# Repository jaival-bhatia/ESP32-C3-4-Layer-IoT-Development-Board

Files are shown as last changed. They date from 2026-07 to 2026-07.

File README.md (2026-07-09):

# ESP32-C3-4-Layer-IoT-Development-Board
A custom-designed 4-layer ESP32-C3 IoT development board featuring USB Type-C, Li-ion battery management, environmental sensing, OLED display, and expandable peripheral interfaces.

<div align="center">

PCB Render

**A Custom 4-Layer ESP32-C3 Development Board for Battery-Powered IoT Applications**

[]()
[]()
[]()
[]()
[]()
[]()

</div>

---

# Overview

This project presents a **custom-designed 4-layer ESP32-C3 IoT Development Board** built for low-power, battery-operated embedded applications. The board combines wireless connectivity, intelligent power management, onboard environmental sensing, expandable storage, and a compact PCB layout into a single development platform.

The primary objective of this project was to design a production-ready embedded hardware platform capable of supporting rapid IoT prototyping while following professional PCB design practices such as dedicated power and ground planes, optimized signal routing, proper decoupling, and manufacturing-ready documentation.

Designed entirely in **KiCad**, the board integrates battery charging, USB Type-C connectivity, environmental sensing, local data storage, and display capabilities, making it suitable for a wide range of embedded applications.

---

# Key Features

- 4-Layer PCB designed using KiCad
- ESP32-C3 Wi-Fi + Bluetooth Low Energy (BLE) SoC
- USB Type-C interface for programming and charging
- TP4056 Li-ion battery charging circuit
- Single-cell Li-ion battery support
- Onboard BME280 environmental sensor
- Ambient Light Sensor
- Sound Sensor Interface
- I²C OLED Display Connector
- SPI Flash Memory
- MicroSD Card Storage
- Battery Status LEDs
- Low-Power Embedded Design
- Expandable GPIO Header
- Manufacturing Ready (ERC/DRC Verified)

---

# Hardware Specifications

| Parameter | Description |
|---|---|
| Microcontroller | ESP32-C3 |
| PCB Layers | 4 |
| Power Input | USB Type-C |
| Battery | 3.7V Li-ion |
| Charging IC | TP4056 |
| Connectivity | Wi-Fi + BLE |
| Display | OLED (I²C) |
| Sensors | BME280, Ambient Light, Sound |
| Storage | SPI Flash + microSD |
| Design Software | KiCad |

---

# System Architecture

```
                  USB Type-C
                       │
                       ▼
                TP4056 Charger
                       │
         ┌─────────────┴─────────────┐
         │                           │
         ▼                           ▼
   Li-ion Battery              USB Power
         │                           │
         └─────────────┬─────────────┘
                       ▼
                 3.3V Regulation
                       │
                       ▼
                  ESP32-C3 MCU
      ┌────────┬────────┬────────┬────────┐
      │        │        │        │
      ▼        ▼        ▼        ▼
   OLED     BME280   Flash    microSD
      │
      ▼
 Additional Sensors & GPIO Expansion
```

---

# Power Architecture

The board supports dual power operation through USB Type-C and a rechargeable Li-ion battery.

Power flow:

```
USB Type-C
      │
      ▼
TP4056 Charger
      │
      ▼
Li-ion Battery
      │
      ▼
Voltage Regulation
      │
      ▼
ESP32-C3 + Peripherals
```

The TP4056 charging IC provides:

- Constant Current Charging
- Constant Voltage Charging
- Automatic Charge Termination
- Thermal Protection
- Battery Status Indication

This enables safe battery charging while simultaneously powering the embedded system.

---

# Major Components

| Component | Function |
|---|---|
| ESP32-C3 | Main Microcontroller |
| TP4056 | Li-ion Battery Charger |
| USB Type-C | Power & Programming |
| BME280 | Temperature, Humidity & Pressure |
| OLED Display | Real-time Visualization |
| Flash Memory | Firmware/Data Storage |
| microSD | External Data Logging |

---

# PCB Design Highlights

Highlights include:

- 4-Layer PCB Stack-up
- Dedicated Ground Plane
- Dedicated Power Plane
- Optimized Component Placement
- Short High-Speed Signal Routing
- Proper Decoupling Capacitor Placement
- Optimized Power Distribution
- Low-Noise Analog Routing
- Manufacturing Ready Layout
- ERC & DRC Verified

## Schematics

| Sheet | Description |
|---|---|
| Sheet 1 | USB Type-C & Power Input |
| Sheet 2 | ESP32-C3 Core Circuit |
| Sheet 3 | Sensors & Interfaces |
| Sheet 4 | Battery Charging & Peripheral Connections |






PCB 1st Layer


PCB 2nd Layer


PCB 3rd Layer


PCB 4th Layer


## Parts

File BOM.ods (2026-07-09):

DESIGNATOR | QTY | VALUE | MANUF. PART No | MANUFACTURER | PACKAGE | DESCRIPTION
C1, C2, C5, C8, C10, C13-C16, C18, C21, C23 | 12 | 0.1u | C0805C104K4RAC | KEMET | 0805 | Multilayer Ceramic Capacitors MLCC - SMD/SMT 16V 0.1uF X7R 0805 10%
C3, C4, C7, C12 | 4 | 10u | T491A106K010AT7280 | KEMET | 1206 | T491, Tantalum, MnO2 Tantalum, Commercial Grade, 10 uF, 10%, 10 VDC, 125C, -55C, 85C, SMD, MnO2, Molded, 6 % , 3.8 Ohms, 1000 nA, 58.6 mg, 3216, 1.6mm, Height Max = 1.8mm, 9000, 156 Weeks
C6, C11, C22 | 3 | 1u | C0805C105K4RACTU | KEMET | 0805 | Multilayer Ceramic Capacitors MLCC - SMD/SMT 16V 1uF X7R 0805 10%
C9 | 1 | 4.7u | T491A475K010AT7280 | KEMET | 1206 | T491, Tantalum, MnO2 Tantalum, Commercial Grade, 4.7 uF, 10%, 10 VDC, 125C, -55C, 85C, SMD, MnO2, Molded, 6 % , 4 Ohms, 500 nA, 58.6 mg, 3216, 1.6mm, Height Max = 1.8mm, 9000, 156 Weeks
C17, C24, C25 | 3 | 10n | C0603C103K4RACTU | KEMET | 0603 | Multilayer Ceramic Capacitors MLCC - SMD/SMT 16V 0.01uF X7R 0603 10%
C19 | 1 | 10uF | C1206C106K4RAC | KEMET | 1206 | Multilayer Ceramic Capacitors MLCC - SMD/SMT 16V 10uF X7R 1206 10%
C20 | 1 | 100pF | C0603C101K4RACTU | KEMET | 0603 | Multilayer Ceramic Capacitors MLCC - SMD/SMT 16V 100pF X7R 0603 10%
D1, D4, D6 | 3 | RED | LTST-C170KRKT | Lite-On | 0805 | Standard LEDs - SMD Red Clear 631nm
D2, D5 | 2 | GREEN | LTST-C170GKT | Lite-On | 0805 | LED,SMD,0805,Green,6mcd,130deg Lite-On LTST-C170GKT, CHIPLED 0805 Series Green LED, 569 nm 2012 (0805), Rectangle Lens SMD package
D3 | 1 | BLUE | LTST-C170TBKT | Lite-On | 0805 | LED,SMD,0805,Blue,28mcd,130deg
F1 | 1 | 0ZCH0110AF2E | 0ZCH0110AF2E | Belfuse | 1210 | 1210 SMT PPTC | 1.10 Ih | 16V
J1 | 1 | USB_C_Receptacle | SS-52400-002 | STEWART CONNECTOR | USB Type-C | USB 2.0-only Type-C Receptacle connector
J2 | 1 | JST_2mm_LiPo | PHR-2 | JST |  | 2 Pin 2mm JST Battery Connector
J3 | 1 | GSD090012SEU | GSD090012SEU | Amphenol |  | Memory Card Connectors SD CARD CONNECTOR 9 POS, SMT
J4, J5 | 2 | B4B-XH-AM | B4B-XH-AM | JST |  | Connector header vertical 4pos 2.5mm
J6 | 1 | Conn_01x05 |  |  |  | Header 1X5, 2.54mm
L1 | 1 |  | FBMJ2125HM330 | TAIYO YUDEN | 0805 | Ferrite Bead 0805 4A 33OHMS 25%
MK1 | 1 | CMC-5042PF-AC | CMC-5042PF-AC | CUI INC
Q1 | 1 | TEMT6000X01 | TEMT6000X01 | VISHAY | 4 mm x 2 mm x 1.05 mm | Ambient Light Sensors Ambient Light Sensor AEC-Q101 Qualified
Q2, Q3 | 2 | BC817 | BC817 |  | SOT-23 | 0.8A Ic, 45V Vce, NPN Transistor, SOT-23
R1, R2, R19, R23, R32-R34 | 7 | 10K |  |  | 805 | SMD resistor, 0805, 125mW, 1%
R3, R4 | 2 | 5k1 |  |  | 0805 | SMD resistor, 0805, 125mW, 1%
R5, R26, R28 | 3 | 2K |  |  | 0805 | SMD resistor, 0805, 125mW, 1%
R6 | 1 | 20K |  |  | 0805 | SMD resistor, 0805, 125mW, 1%
R7-R9 | 3 | 470 |  |  | 0805 | SMD resistor, 0805, 125mW, 1%
R10, R14, R18 | 3 | 330 |  |  | 0805 | SMD resistor, 0805, 125mW, 1%
R11, R30 | 2 | 1K |  |  | 0805 | SMD resistor, 0805, 125mW, 1%
R12 | 1 | 22K1 |  |  | 0805 | SMD resistor, 0805, 125mW, 1%
R13 | 1 | 47K5 |  |  | 0805 | SMD resistor, 0805, 125mW, 1%
R15-R17, R20-R22 | 6 | 50 |  |  | 0805 | SMD resistor, 0805, 125mW, 1%
R24, R25 | 2 | 4K7 |  |  | 0805 | SMD resistor, 0805, 125mW, 1%
R27, R29 | 2 | 1M |  |  | 0805 | SMD resistor, 0805, 125mW, 1%
R31 | 1 | 22K |  |  | 0805 | SMD resistor, 0805, 125mW, 1%
SW1, SW2 | 2 | TL3305AF260QG | TL3305AF260QG | E-Switch |  | Tactile Switches 50mA 12VDC SPST, NO 3.8mm Act 260gf
U1 | 1 | MCP73871 | MCP73871-4CCI/ML | Microchip | QFN-20 | Single cell, Li-Ion/Li-Po charge management controller
U2 | 1 | LM1117MPX-3.3_NOPB | LM1117MPX-3.3/NOPB | Texas Instruments | SOT-223-4 | Space saving 800-mA low-dropout linear regulator with internal current limit
U3 | 1 | ESP32-C3-WROOM-02-H4 | ESP32-C3-WROOM-02-H4 | Espressif |  | Multiprotocol Modules SMD module, ESP32-C3, 4MB SPI flash, PCB antenna
U4 | 1 | CP2102N-A02-GQFN20 | CP2102N-A02-GQFN20 | Silicon Laboratories | QFN20 | USB to UART Bridge
U5 | 1 | USBLC6-2SC6 | USBLC6-2SC6 | STMicroelectronics | SOT-23-6 | ESD Suppressors / TVS Diodes ESD Protection Low Cap
U6 | 1 | W25Q32JVSSIQ | W25Q32JVSSIQ | Winbond | SOIC-8 | NOR Flash spiFlash, 32M-bit, 4Kb Uniform Sector
U7 | 1 | BME280 | BME280 | Bosch | LGA-8 | Air Quality Sensor MEMS humidity, pressure and temperature sensor
U8 | 1 | MAX4466EXK+T | MAX4466EXK+T | Analog Devices Inc. | SC-70-5 | Microphone Preamplifier
VR1 | 1 | 35WR100KLFTR | 35WR100KLFTR | TT Electronics |  | Trimmer Resistor - SMD 3mm 100K Open Type

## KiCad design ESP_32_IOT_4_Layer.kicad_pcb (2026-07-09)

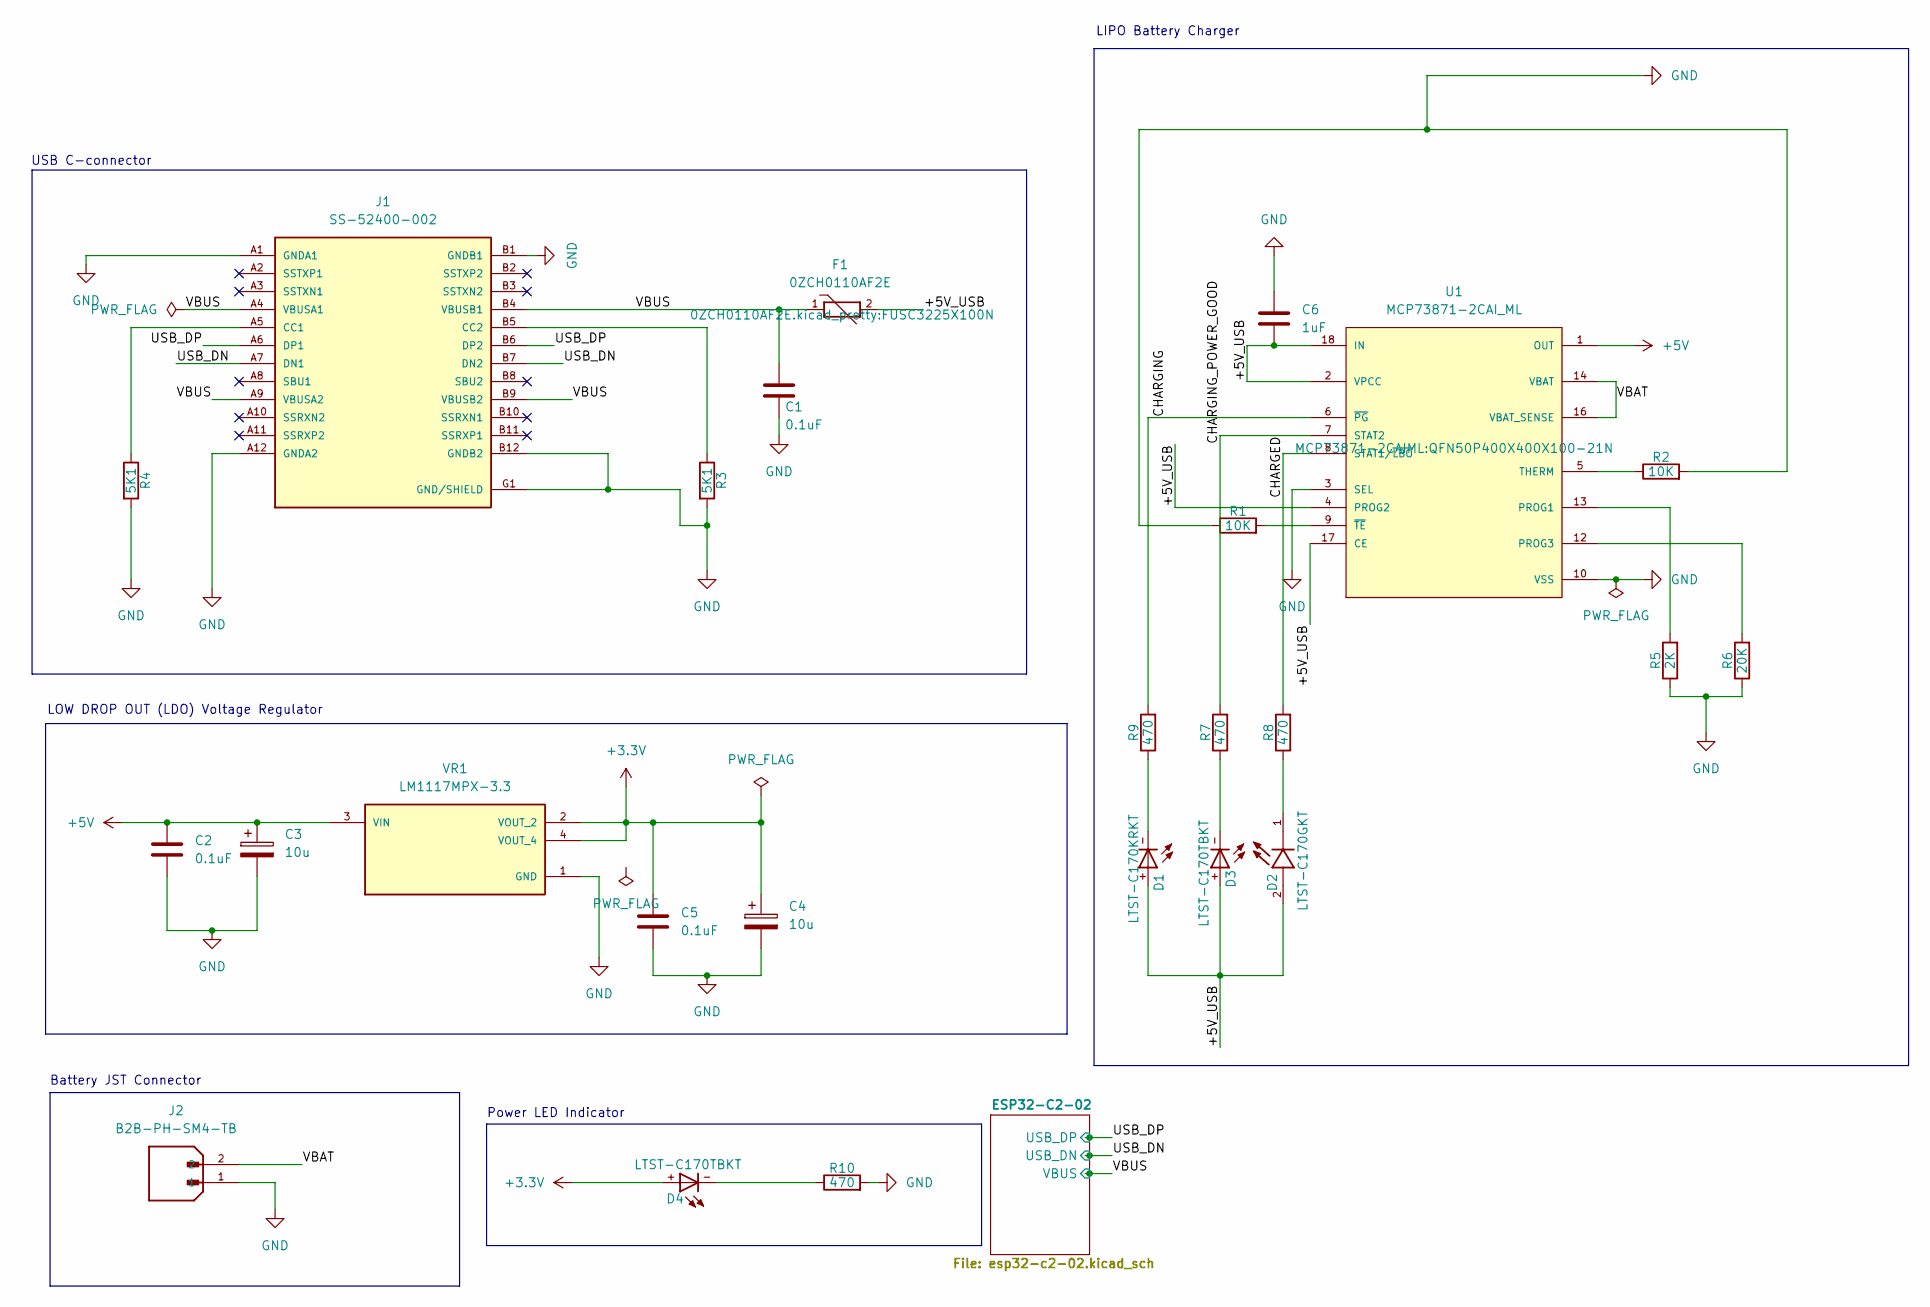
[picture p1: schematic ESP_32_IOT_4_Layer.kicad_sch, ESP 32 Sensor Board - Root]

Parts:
C1, C2, C5: 0.1uF; Fuse_0805_2012Metric
C3, C4: 10u; Fuse_0805_2012Metric
C6: 1uF; Fuse_0805_2012Metric
D1: LTST-C170KRKT; DIOC200X125X110; DigiKey_Part_Number 160-1415-1-ND
D2: LTST-C170GKT; LED_LTST-C170GKT; PARTREV I; DigiKey_Part_Number 160-1179-1-ND
D3, D4: LTST-C170TBKT; DIOC200X125X110; DigiKey_Part_Number 160-1579-1-ND
F1: 0ZCH0110AF2E; FUSC3225X100N; PARTREV Apr2023; DigiKey_Part_Number 5923-0ZCH0110AF2ECT-ND
J1: SS-52400-002; BELFUSE_SS-52400-003; PARTREV A0
J2: B2B-PH-SM4-TB; JST_B2B-PH-SM4-TB; PARTREV N/A
R1, R2: 10K; R_0805_2012Metric
R3, R4: 5K1; R_0805_2012Metric
R5: 2K; R_0805_2012Metric
R6: 20K; R_0805_2012Metric
R7, R8, R9, R10: 470; R_0805_2012Metric
U1: MCP73871-2CAI_ML; QFN50P400X400X100-21N; PARTREV D
VR1: LM1117MPX-3.3; VREG_LM1117MPX-3.3; PARTREV O

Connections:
+3.3V: C4.1, C5.1, D4.+, VR1.2 (VOUT_2), VR1.4 (VOUT_4); also elsewhere on the board
+5V: C2.1, C3.1, U1.1 (OUT), U1.20 (OUT), VR1.3 (VIN)
/+5V_USB: C6.2, D1.+, D2.2, D3.+, F1.2, U1.2 (VPCC), U1.4 (PROG2), U1.17 (CE), U1.18 (IN), U1.19 (IN)
/CHARGED: R8.2, U1.8 (STAT1/~LBO)
/CHARGING: R9.2, U1.6 (~PG)
/CHARGING_POWER_GOOD: R7.2, U1.7 (STAT2)
/USB_DN: J1.A7 (DN1), J1.B7 (DN2); also elsewhere on the board
/USB_DP: J1.A6 (DP1), J1.B6 (DP2); also elsewhere on the board
/VBAT: J2.2, U1.14 (VBAT), U1.15 (VBAT), U1.16 (VBAT_SENSE)
/VBUS: C1.1, F1.1, J1.A4 (VBUSA1), J1.A9 (VBUSA2), J1.B4 (VBUSB1), J1.B9 (VBUSB2); also elsewhere on the board
GND: C1.2, C2.2, C3.2, C4.2, C5.2, C6.1, J1.A1 (GNDA1), J1.A12 (GNDA2), J1.B1 (GNDB1), J1.B12 (GNDB2), J1.G1 (GND/SHIELD), J1.G2 (GND/SHIELD), J1.G3 (GND/SHIELD), J1.G4 (GND/SHIELD), J1.S1 (GND/SHIELD), J1.S2 (GND/SHIELD), J1.S3 (GND/SHIELD), J1.S4 (GND/SHIELD), J2.1, R1.1, R2.2, R3.2, R4.2, R5.1, R6.1, R10.2, U1.3 (SEL), U1.10 (VSS), U1.11 (VSS), U1.21 (VSS), VR1.1 (GND); also elsewhere on the board
unnamed: D1.-, R9.1
unnamed: D2.1, R8.1
unnamed: D3.-, R7.1
unnamed: D4.-, R10.1
unnamed: J1.A5 (CC1), R4.1
unnamed: J1.B5 (CC2), R3.1
unnamed: R5.2, U1.13 (PROG1)
unnamed: R6.2, U1.12 (PROG3)
unnamed: R2.1, U1.5 (THERM)
unnamed: R1.2, U1.9 (~TE)

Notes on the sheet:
LOW DROP OUT (LDO) Voltage Regulator
Power LED Indicator
Battery JST Connector
USB C-connector
LIPO Battery Charger

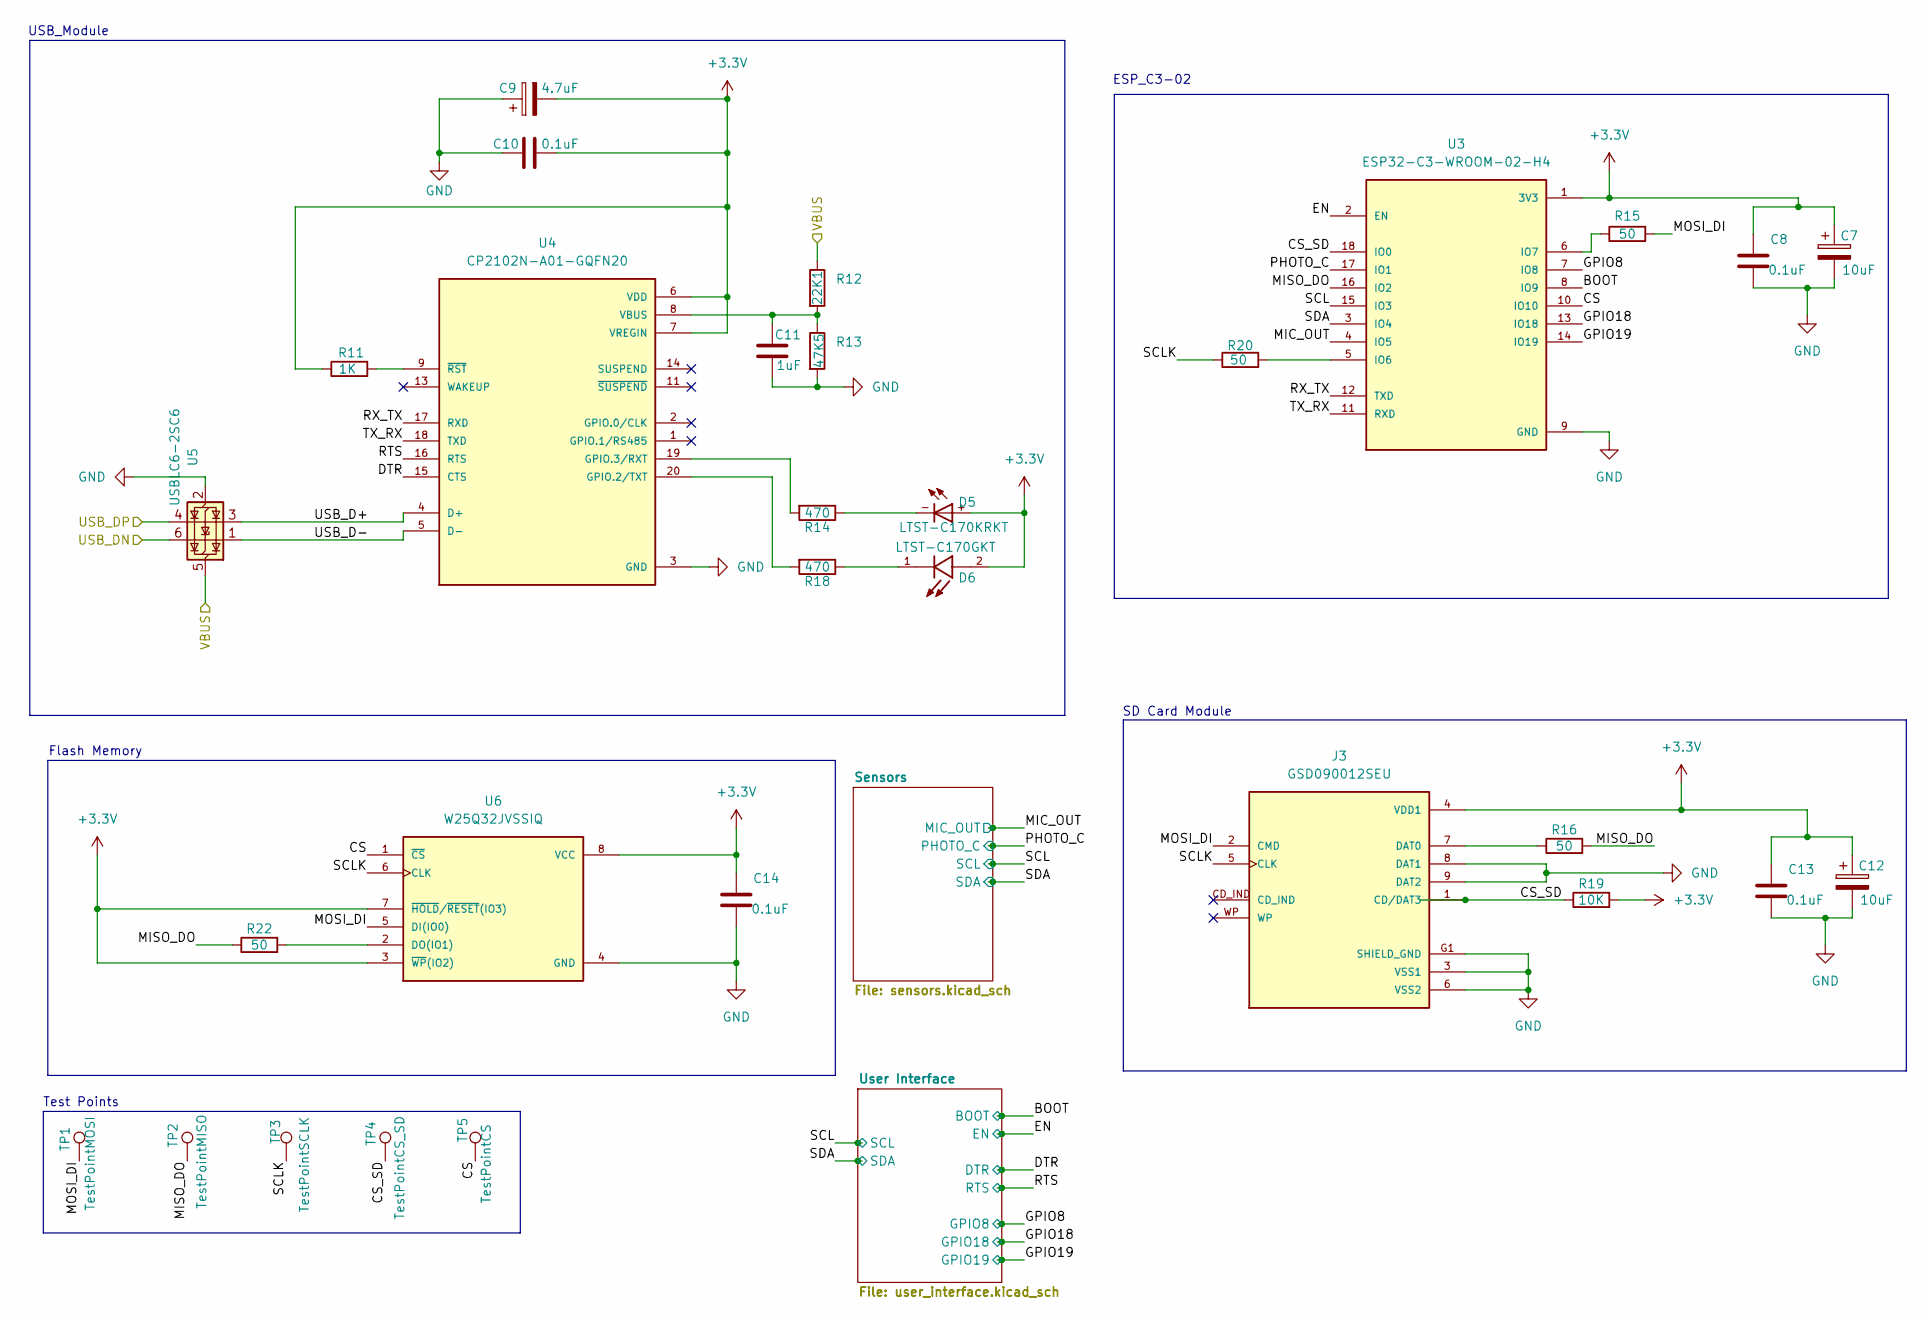
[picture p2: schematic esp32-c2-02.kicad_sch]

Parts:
C7, C12: 10uF; Fuse_0805_2012Metric
C8, C10, C13, C14: 0.1uF; Fuse_0805_2012Metric
C9: 4.7uF; Fuse_0805_2012Metric
C11: 1uF; Fuse_0805_2012Metric
D5: LTST-C170KRKT; DIOC200X125X110; DigiKey_Part_Number 160-1415-1-ND
D6: LTST-C170GKT; LED_LTST-C170GKT; PARTREV I; DigiKey_Part_Number 160-1179-1-ND
J3: GSD090012SEU; AMPHENOL_GSD090012SEU; PARTREV E
R11: 1K; R_0805_2012Metric
R12: 22K1; R_0805_2012Metric
R13: 47K5; R_0805_2012Metric
R14, R18: 470; R_0805_2012Metric
R15, R16, R20, R22: 50; R_0805_2012Metric
R19: 10K; R_0805_2012Metric
TP1: TestPointMOSI; TestPoint_Pad_D1.0mm
TP2: TestPointMISO; TestPoint_Pad_D1.0mm
TP3: TestPointSCLK; TestPoint_Pad_D1.0mm
TP4: TestPointCS_SD; TestPoint_Pad_D1.0mm
TP5: TestPointCS; TestPoint_Pad_D1.0mm
U3: ESP32-C3-WROOM-02-H4; MODULE_ESP32-C3-WROOM-02-H4
U4: CP2102N-A01-GQFN20; IC_CP2102N-A01-GQFN20
U5: USBLC6-2SC6; SOT95P280X145-6N
U6: W25Q32JVSSIQ; SOIC127P790X216-8N

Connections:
+3.3V: C7.1, C8.1, C9.2, C10.2, C12.1, C13.1, C14.1, D5.+, D6.2, J3.4 (VDD1), R11.1, R19.2, U3.1 (3V3), U4.6 (VDD), U4.7 (VREGIN), U6.3 (~WP(IO2)), U6.7 (~HOLD/~RESET(IO3)), U6.8 (VCC); also elsewhere on the board
/ESP32-C2-02/BOOT: U3.8 (IO9); also elsewhere on the board
/ESP32-C2-02/CS: TP5.1 (1_1), U3.10 (IO10), U6.1 (~CS)
/ESP32-C2-02/CS_SD: J3.1 (CD/DAT3), R19.1, TP4.1 (1_1), U3.18 (IO0)
/ESP32-C2-02/DTR: U4.15 (CTS); also elsewhere on the board
/ESP32-C2-02/EN: U3.2 (EN); also elsewhere on the board
/ESP32-C2-02/GPIO8: U3.7 (IO8); also elsewhere on the board
/ESP32-C2-02/GPIO18: U3.13 (IO18); also elsewhere on the board
/ESP32-C2-02/GPIO19: U3.14 (IO19); also elsewhere on the board
/ESP32-C2-02/MIC_OUT: U3.4 (IO5); also elsewhere on the board
/ESP32-C2-02/MISO_DO: R16.2, R22.1, TP2.1 (1_1), U3.16 (IO2)
/ESP32-C2-02/MOSI_DI: J3.2 (CMD), R15.2, TP1.1 (1_1), U6.5 (DI(IO0))
/ESP32-C2-02/PHOTO_C: U3.17 (IO1); also elsewhere on the board
/ESP32-C2-02/RTS: U4.16 (RTS); also elsewhere on the board
/ESP32-C2-02/RX_TX: U3.12 (TXD), U4.17 (RXD)
/ESP32-C2-02/SCL: U3.15 (IO3); also elsewhere on the board
/ESP32-C2-02/SCLK: J3.5 (CLK), R20.1, TP3.1 (1_1), U6.6 (CLK)
/ESP32-C2-02/SDA: U3.3 (IO4); also elsewhere on the board
/ESP32-C2-02/TX_RX: U3.11 (RXD), U4.18 (TXD)
/ESP32-C2-02/USB_D+: U4.4 (D+), U5.3 (I/O2)
/ESP32-C2-02/USB_D-: U4.5 (D-), U5.1 (I/O1)
/USB_DN: U5.6 (I/O1); also elsewhere on the board
/USB_DP: U5.4 (I/O2); also elsewhere on the board
/VBUS: R12.1, U5.5 (VBUS); also elsewhere on the board
GND: C7.2, C8.2, C9.1, C10.1, C11.2, C12.2, C13.2, C14.2, J3.3 (VSS1), J3.6 (VSS2), J3.8 (DAT1), J3.9 (DAT2), J3.G1 (SHIELD_GND), J3.G2 (SHIELD_GND), J3.G3 (SHIELD_GND), J3.G4 (SHIELD_GND), R13.2, U3.9 (GND), U3.19 (GND), U3.20 (GND), U3.21 (GND), U3.22 (GND), U3.23 (GND), U3.24 (GND), U3.25 (GND), U3.26 (GND), U3.27 (GND), U3.28 (GND), U3.29 (GND), U3.30 (GND), U3.31 (GND), U3.32 (GND), U3.33 (GND), U3.34 (GND), U3.35 (GND), U3.36 (GND), U3.37 (GND), U3.38 (GND), U3.39 (GND), U4.3 (GND), U4.12 (GND), U4.21 (GND), U5.2 (GND), U6.4 (GND); also elsewhere on the board
unnamed: D5.-, R14.1
unnamed: D6.1, R18.1
unnamed: J3.7 (DAT0), R16.1
unnamed: R20.2, U3.5 (IO6)
unnamed: R15.1, U3.6 (IO7)
unnamed: R18.2, U4.20 (GPIO.2/TXT)
unnamed: R14.2, U4.19 (GPIO.3/RXT)
unnamed: C11.1, R12.2, R13.1, U4.8 (VBUS)
unnamed: R11.2, U4.9 (~RST)
unnamed: R22.2, U6.2 (DO(IO1))

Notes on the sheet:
ESP_C3-02
USB_Module
Test Points
SD Card Module
Flash Memory

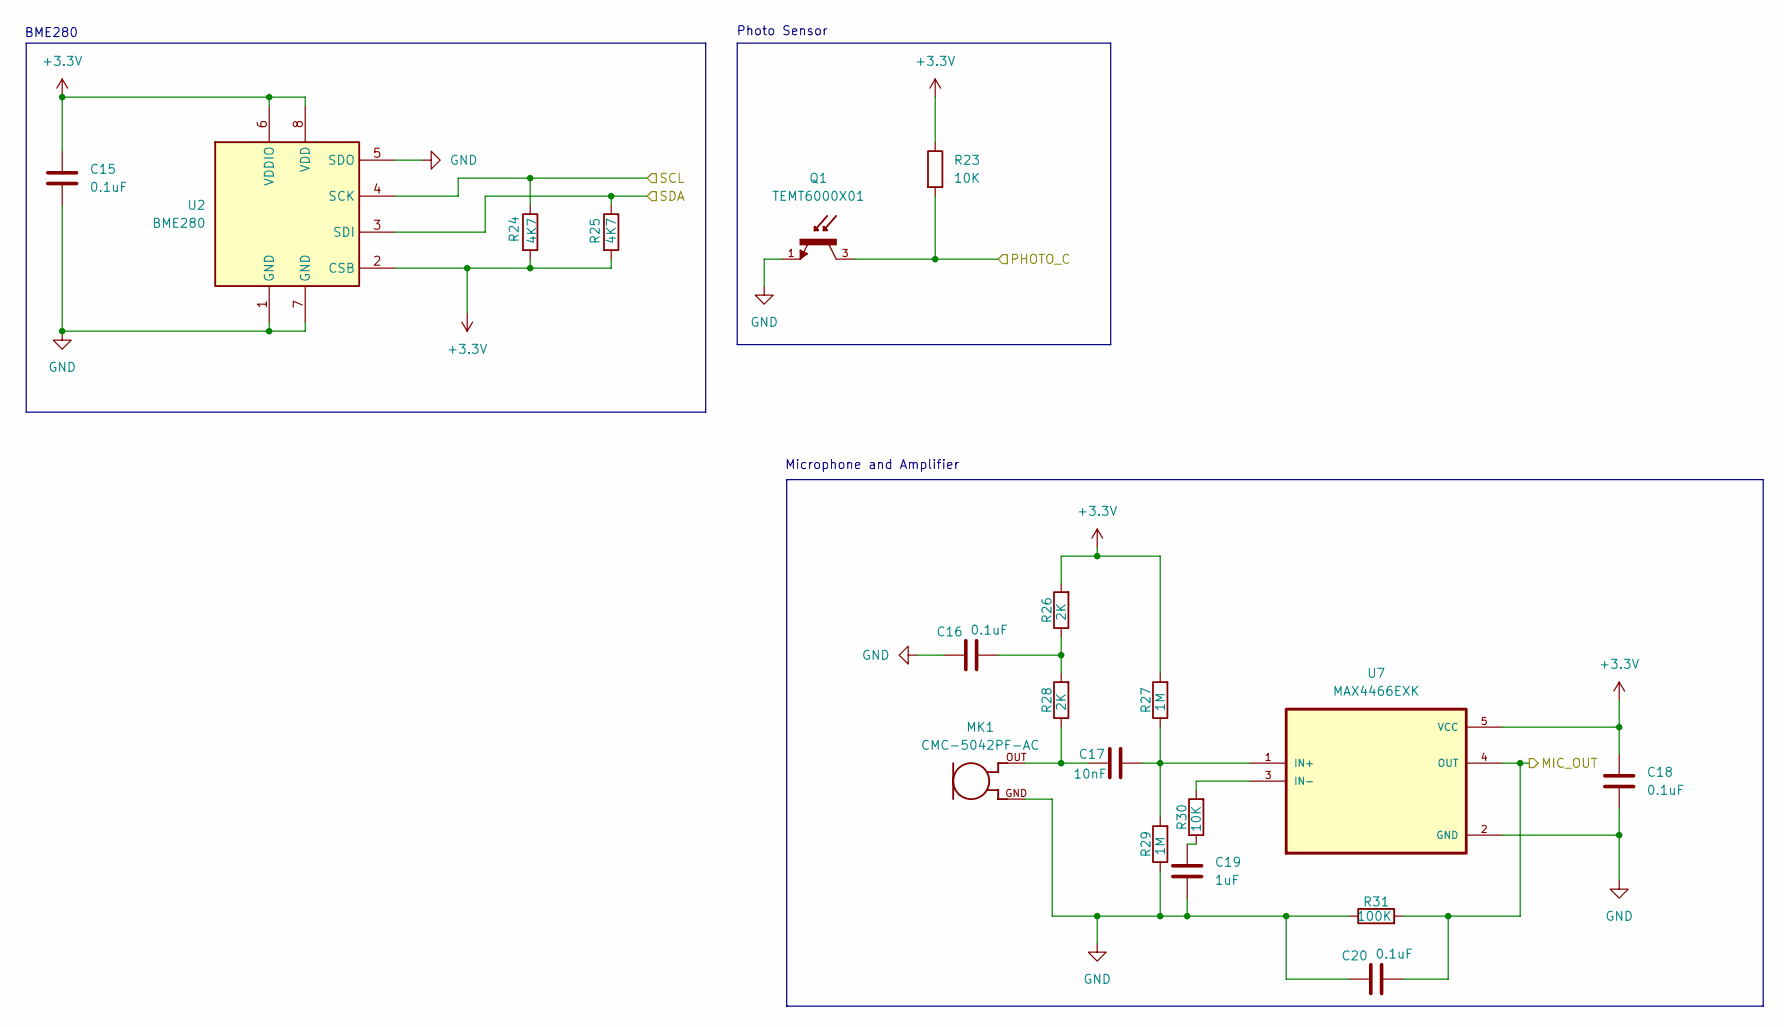
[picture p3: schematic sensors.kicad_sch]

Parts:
C15, C16, C18, C20: 0.1uF; Fuse_0805_2012Metric
C17: 10nF; Fuse_0805_2012Metric
C19: 1uF; Fuse_0805_2012Metric
MK1: CMC-5042PF-AC; CUI_CMC-5042PF-AC
Q1: TEMT6000X01; TRANS_TEMT6000X01; PARTREV 1.9
R23, R30: 10K; R_0805_2012Metric
R24, R25: 4K7; R_0805_2012Metric
R26, R28: 2K; R_0805_2012Metric
R27, R29: 1M; R_0805_2012Metric
R31: 100K; R_0805_2012Metric
U2: BME280; PSON65P250X250X100-8N
U7: MAX4466EXK; SOT65P210X110-5N

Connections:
+3.3V: C15.1, C18.1, R23.1, R24.2, R25.2, R26.2, R27.2, U2.2 (CSB), U2.6 (VDDIO), U2.8 (VDD), U7.5 (VCC); also elsewhere on the board
/ESP32-C2-02/MIC_OUT: C20.2, R31.2, U7.4 (OUT); also elsewhere on the board
/ESP32-C2-02/PHOTO_C: Q1.3, R23.2; also elsewhere on the board
/ESP32-C2-02/SCL: R24.1, U2.4 (SCK); also elsewhere on the board
/ESP32-C2-02/SDA: R25.1, U2.3 (SDI); also elsewhere on the board
GND: C15.2, C16.1, C18.2, C19.2, C20.1, MK1.GND, Q1.1, R29.1, R31.1, U2.1 (GND), U2.5 (SDO), U2.7 (GND), U7.2 (GND); also elsewhere on the board
unnamed: C16.2, R26.1, R28.2
unnamed: C17.1, MK1.OUT, R28.1
unnamed: C19.1, R30.1
unnamed: C17.2, R27.1, R29.2, U7.1 (IN+)
unnamed: R30.2, U7.3 (IN-)

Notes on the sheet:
Microphone and Amplifier
Photo Sensor
BME280

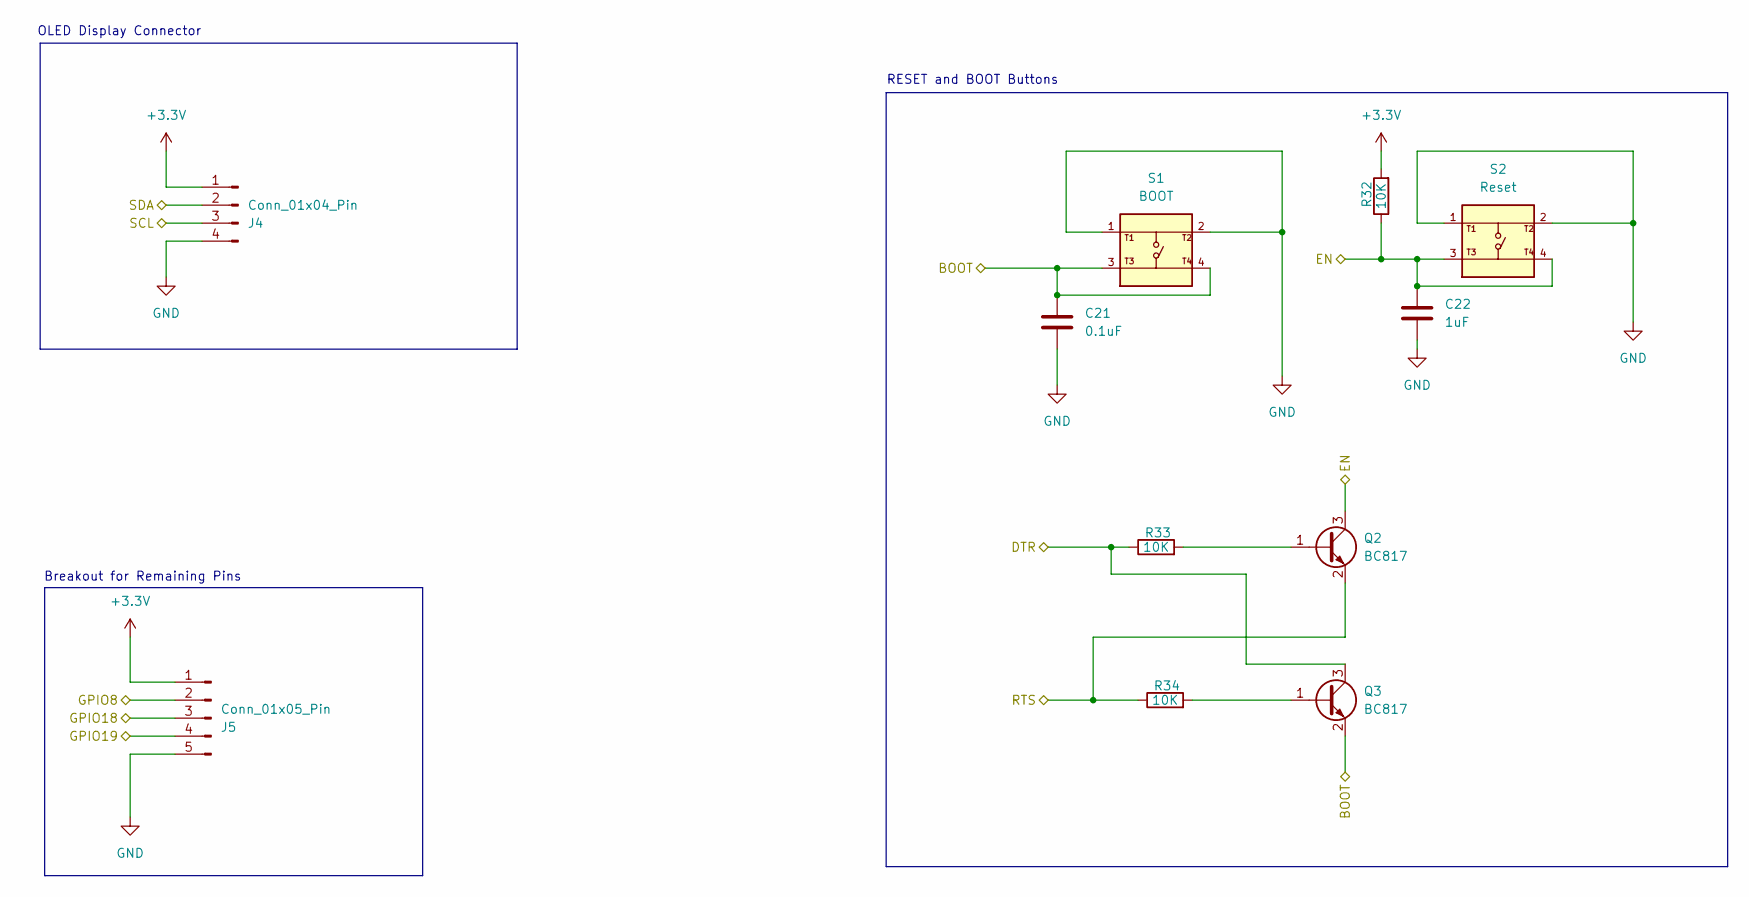
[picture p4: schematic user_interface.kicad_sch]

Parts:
C21: 0.1uF; Fuse_0805_2012Metric
C22: 1uF; Fuse_0805_2012Metric
J4: Conn_01x04_Pin; PinHeader_1x04_P2.54mm_Vertical
J5: Conn_01x05_Pin; PinHeader_1x05_P2.54mm_Vertical
Q2, Q3: BC817; SOT-23
R32, R33, R34: 10K; R_0805_2012Metric
S1: BOOT; SW_USLPT2819DT2TR; PARTREV P
S2: Reset; SW_USLPT2819DT2TR; PARTREV P

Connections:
+3.3V: J4.1, J5.1, R32.2; also elsewhere on the board
/ESP32-C2-02/BOOT: C21.1, Q3.2 (E), S1.3, S1.4; also elsewhere on the board
/ESP32-C2-02/DTR: Q3.3 (C), R33.1; also elsewhere on the board
/ESP32-C2-02/EN: C22.1, Q2.3 (C), R32.1, S2.3, S2.4; also elsewhere on the board
/ESP32-C2-02/GPIO8: J5.2; also elsewhere on the board
/ESP32-C2-02/GPIO18: J5.3; also elsewhere on the board
/ESP32-C2-02/GPIO19: J5.4; also elsewhere on the board
/ESP32-C2-02/RTS: Q2.2 (E), R34.1; also elsewhere on the board
/ESP32-C2-02/SCL: J4.3; also elsewhere on the board
/ESP32-C2-02/SDA: J4.2; also elsewhere on the board
GND: C21.2, C22.2, J4.4, J5.5, S1.1, S1.2, S2.1, S2.2; also elsewhere on the board
unnamed: Q2.1 (B), R33.2
unnamed: Q3.1 (B), R34.2

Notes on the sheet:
OLED Display Connector
RESET and BOOT Buttons
Breakout for Remaining Pins

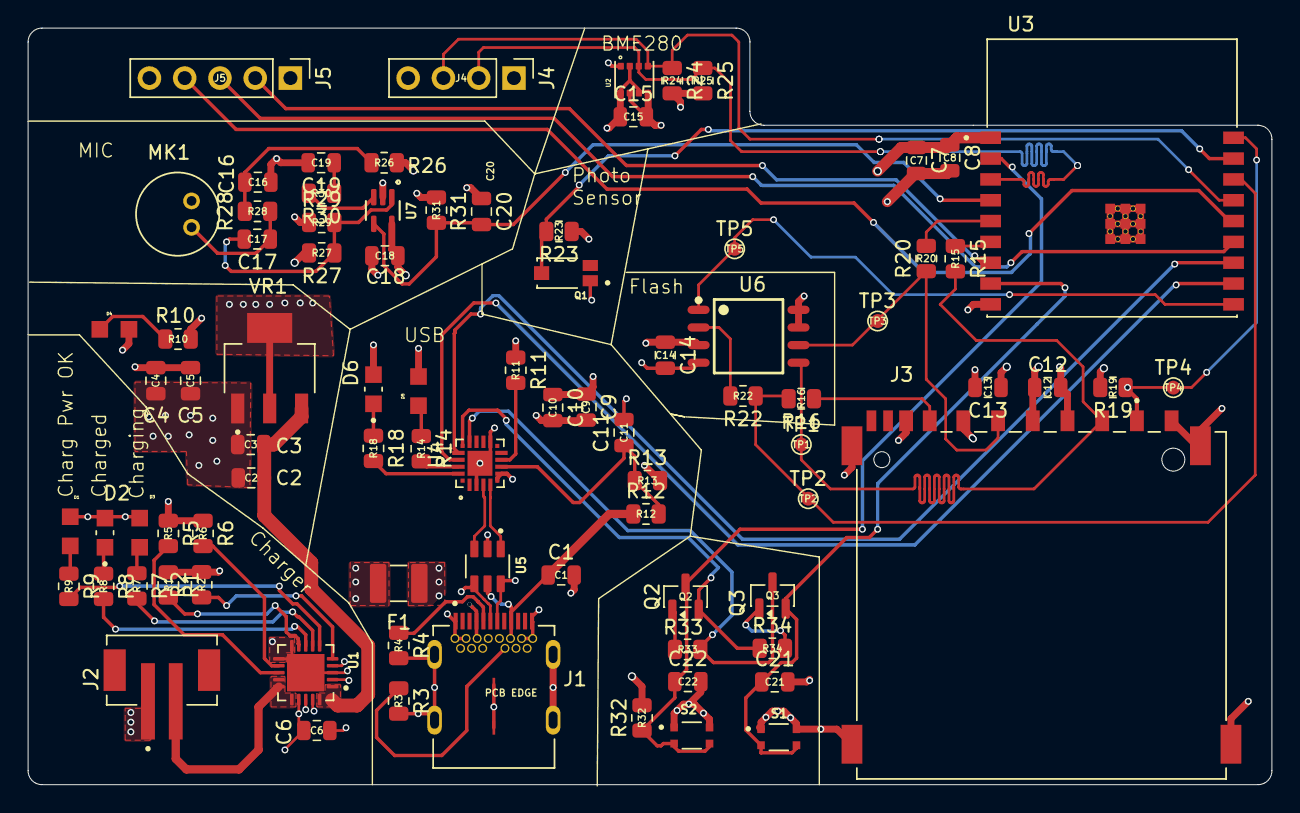
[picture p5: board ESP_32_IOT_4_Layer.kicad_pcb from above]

Board: 4 copper layers, 89.6 x 54.5 mm, 85 parts (0 on the bottom side), 58 nets.

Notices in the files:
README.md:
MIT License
